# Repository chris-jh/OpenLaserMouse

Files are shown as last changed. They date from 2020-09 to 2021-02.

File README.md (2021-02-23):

# Open Laser Mouse
 Quadrature Optical Mouse Replacement Using an Arduino for the Amiga Tank Mouse

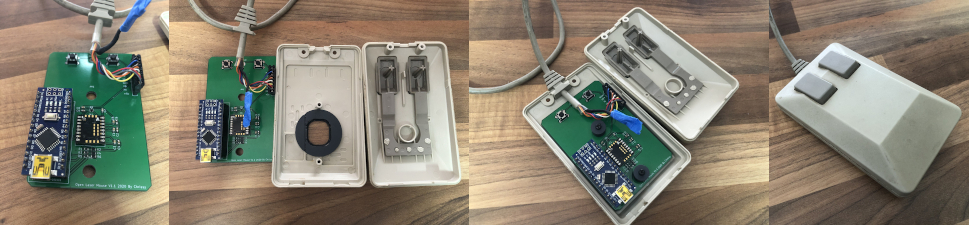
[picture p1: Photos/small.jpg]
PCB


Version 1.4.1
Copyright 2020 Chrissy

* Updated 3D Lens Cover

Version 1.4
Copyright 2020 Chrissy

* Added Atari ST SMD Version
  * Not Tested
  * Arduino is flipped 180° for ST version
  * Use same Amiga Pin definition in Arduino source if using original ST DE9 Connector.
* Fixed Wrong Fillplane selected. Corrected it back to GND.

Version 1.3
Copyright 2020 Chrissy

* ADNS9800 interface based on code from https://github.com/mrjohnk/ADNS-9800
* QUADRATURE interface based on blog from http://danceswithferrets.org/geekblog/?p=742

Two versions of the PCB, a SMD version (v1.1 Tested, not v1.3 yet) and a THT version which is currently untested.

Requires an Arduino Nano and a ADNS9800 Laser, which you can get still get from Aliexpress. Make sure to also get the Lens.

[**SMD Interactive BOM**][IBOMSMD]

[**THT Interactive BOM**][IBOMTHT]

Gerbers have been created from the recommendations at JLCPCB.

(https://support.jlcpcb.com/article/102-kicad-515---generating-gerber-and-drill-files)

You may need to re-generate for your chosen PCB Manufacturer

get the 1.2mm PCB Thickness or get smaller height tact switches if you use 1.6mm thickness. It is a tight tolerance between the tact switch mouse buttons and the posts on the mouse buttons.

---

## 3D Printable Lens Cover

3D Printable Lens Cover still requires testing, Sketchup model file is included to modify for tolerances of your printer.
<br>Only for Amiga SMD Version at the moment

***Print Settings***

* Layer Height : 1.5mm
* Print Speed : 25 mm/s
* Initial Layer Speed: 15mm
* Support: Yes
* Infill: 20%
* Line Width: 0.4mm
* Print Thin Walls: Yes
* Filter Out Tiny Gaps: Yes

3D printed on a Ender 3 using Cura

A fully printable Amiga Tank Mouse is available here

https://www.myminifactory.com/object/3d-print-amiga-tank-mouse-all-parts-are-ultra-detailed-100-size-104702

Although looks tough to print :)

---

## !!!!! WARNING !!!!!
Don't Plug in the USB to the Arduino while connected to the Amiga/Computer, as this will join the 5V together and may damage something.

This is still a work in progress, use at your own risk. I accept no responsibility if this damages any of your equipment.

[IBOMSMD]: http://htmlpreview.github.io/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
[IBOMTHT]: http://htmlpreview.github.io/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

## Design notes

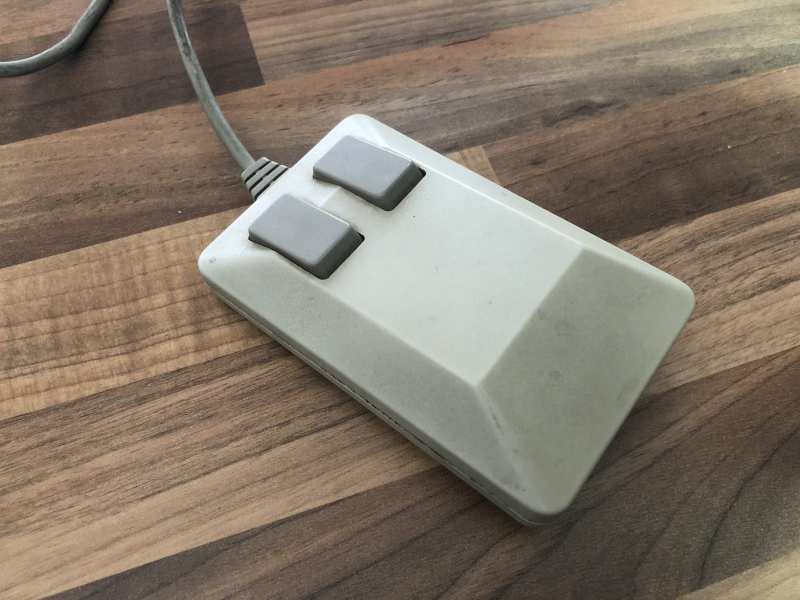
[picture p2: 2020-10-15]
Photos/mouse1.jpg

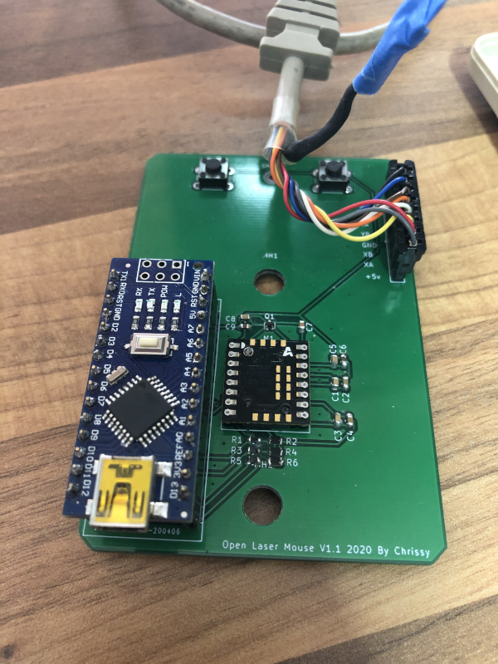
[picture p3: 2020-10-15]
Photos/board_front.jpg

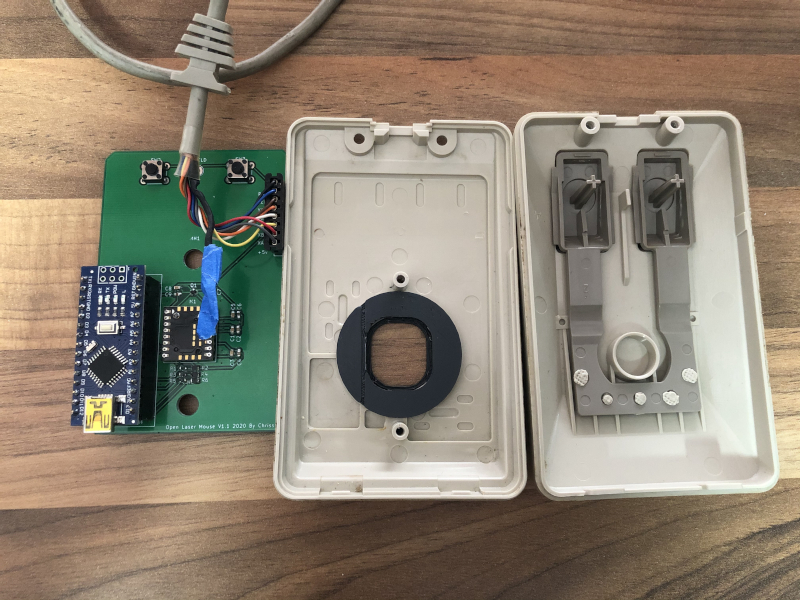
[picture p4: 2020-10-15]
Photos/mouse4.jpg

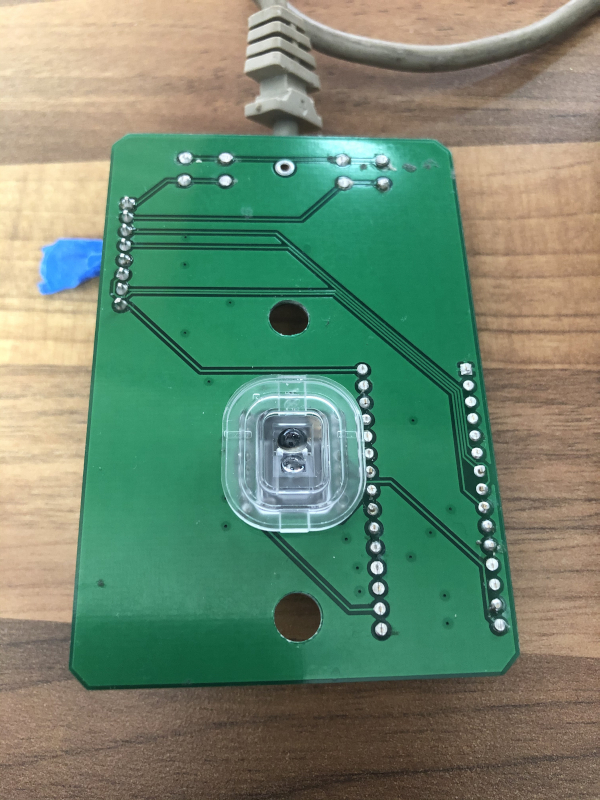
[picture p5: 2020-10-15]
Photos/board_back.jpg

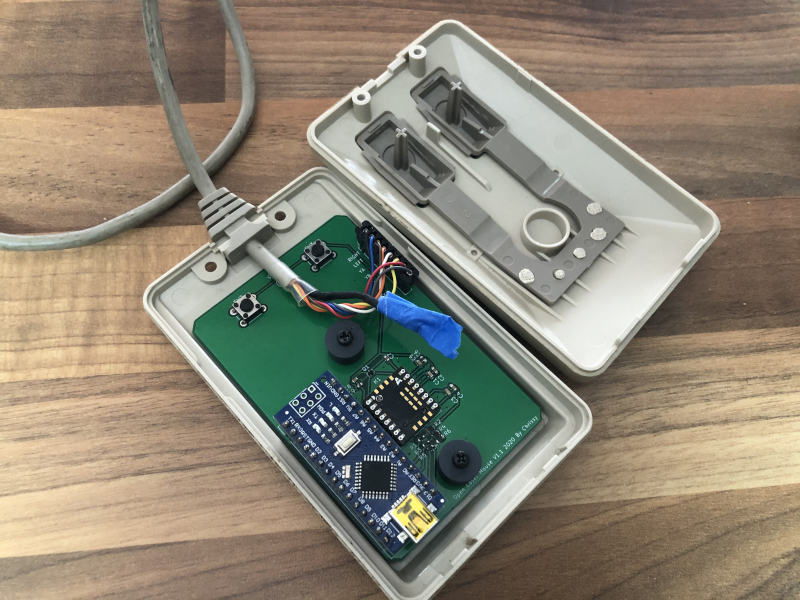
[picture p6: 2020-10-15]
Photos/mouse3.jpg

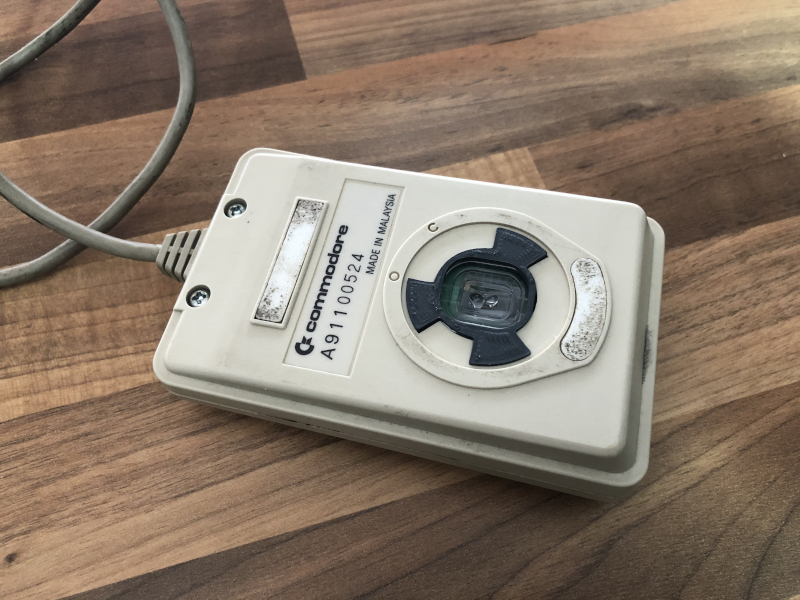
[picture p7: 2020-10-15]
Photos/mouse2.jpg

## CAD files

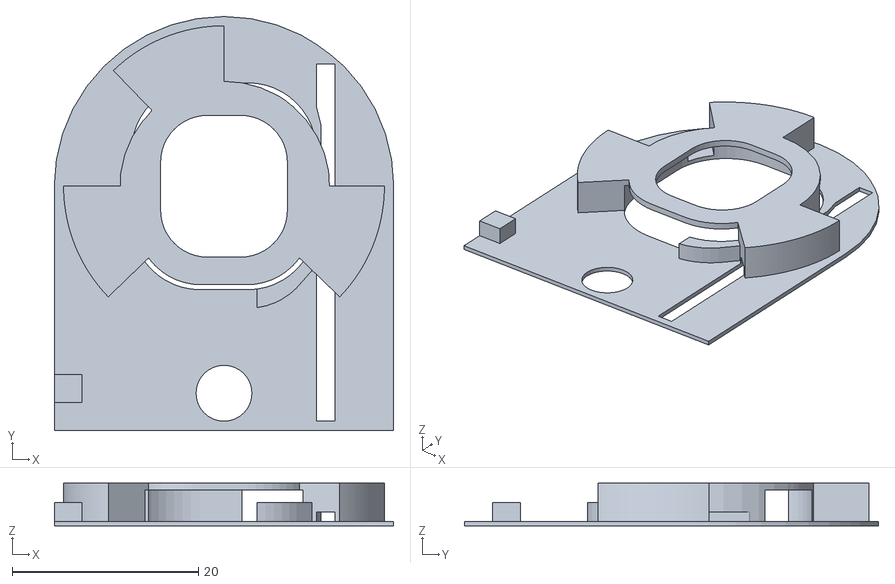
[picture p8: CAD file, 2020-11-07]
MouseLensCover/MouseLensCover.stl
36.5 x 44.4 x 4.60

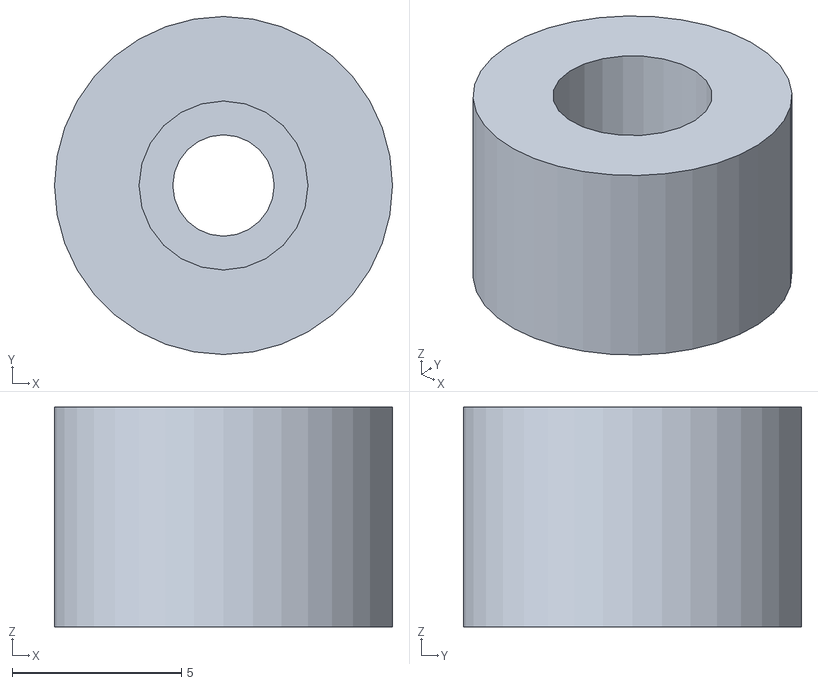
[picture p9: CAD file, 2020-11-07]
MouseLensCover/MouseLensCoverScrewHolder.stl
10.0 x 10.00 x 6.50

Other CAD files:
MouseLensCover/MouseLensCover.skp
MouseLensCover/MouseLensCover~.skp

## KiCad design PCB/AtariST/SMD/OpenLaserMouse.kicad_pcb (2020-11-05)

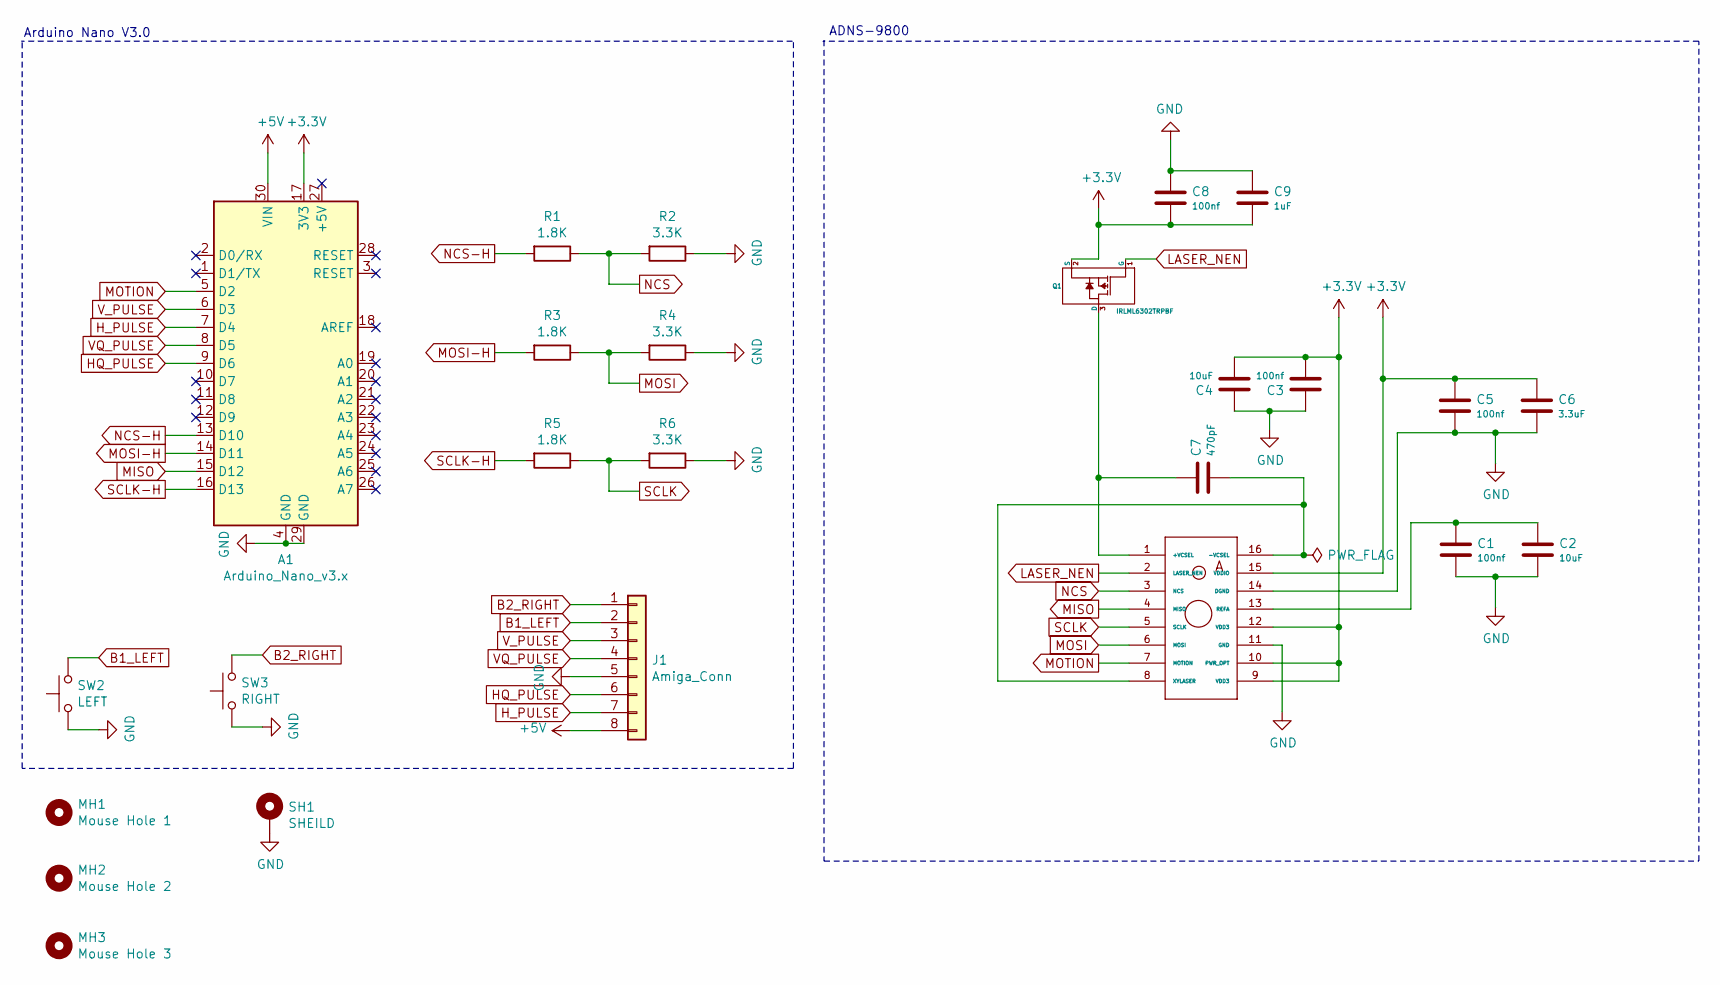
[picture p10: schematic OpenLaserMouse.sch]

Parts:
A1: Arduino_Nano_v3.x; Arduino_Nano
C1, C3, C5, C8: 100nf; C_0805_2012Metric
C2, C4: 10uF; C_0805_2012Metric
C6: 3.3uF; C_0805_2012Metric
C7: 470pF; C_0805_2012Metric
C9: 1uF; C_0805_2012Metric
J1: Amiga_Conn; PinHeader_1x08_P2.54mm_Vertical
M1: ADNS-9800
MH1: Mouse Hole 1; MountingHole_5.3mm_M5
MH2: Mouse Hole 2; MountingHole_5.3mm_M5
MH3: Mouse Hole 3; MountingHole_5.3mm_M5
Q1: IRLML6302TRPBF; SOT-23
R1, R3, R5: 1.8K; R_0805_2012Metric
R2, R4, R6: 3.3K; R_0805_2012Metric
SH1: SHEILD; Pin_D1.3mm_L11.0mm_LooseFit
SW2: LEFT; SW_PUSH_6mm
SW3: RIGHT; SW_PUSH_6mm

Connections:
+3V3: A1.17 (3V3), C3.2, C4.2, C5.1, C6.1, C8.2, C9.2, M1.9 (VDD3), M1.10 (PWR_OPT), M1.12 (VDD3), M1.15 (VDDIO), Q1.2 (S)
+5V: A1.30 (VIN), J1.8
B1_LEFT: J1.2, SW2.2
B2_RIGHT: J1.1, SW3.2
GND: A1.4 (GND), A1.29 (GND), C1.2, C2.2, C3.1, C4.1, C5.2, C6.2, C8.1, C9.1, J1.5, M1.11 (GND), M1.14 (DGND), R2.1, R4.1, R6.1, SH1.1, SW2.1, SW3.1
HQ_PULSE: A1.9 (D6), J1.6
H_PULSE: A1.7 (D4), J1.7
LASER_NEN: M1.2 (LASER_NEN), Q1.1 (G)
MISO: A1.15 (D12), M1.4 (MISO)
MOSI: M1.6 (MOSI), R3.1, R4.2
MOSI-H: A1.14 (D11), R3.2
MOTION: A1.5 (D2), M1.7 (MOTION)
NCS: M1.3 (NCS), R1.1, R2.2
NCS-H: A1.13 (D10), R1.2
unnamed: C1.1, C2.1, M1.13 (REFA)
unnamed: C7.1, M1.1 (+VCSEL), Q1.3 (D)
unnamed: C7.2, M1.8 (XYLASER), M1.16 (-VCSEL)
SCLK: M1.5 (SCLK), R5.1, R6.2
SCLK-H: A1.16 (D13), R5.2
VQ_PULSE: A1.8 (D5), J1.4
V_PULSE: A1.6 (D3), J1.3

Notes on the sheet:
ADNS-9800
Arduino Nano V3.0

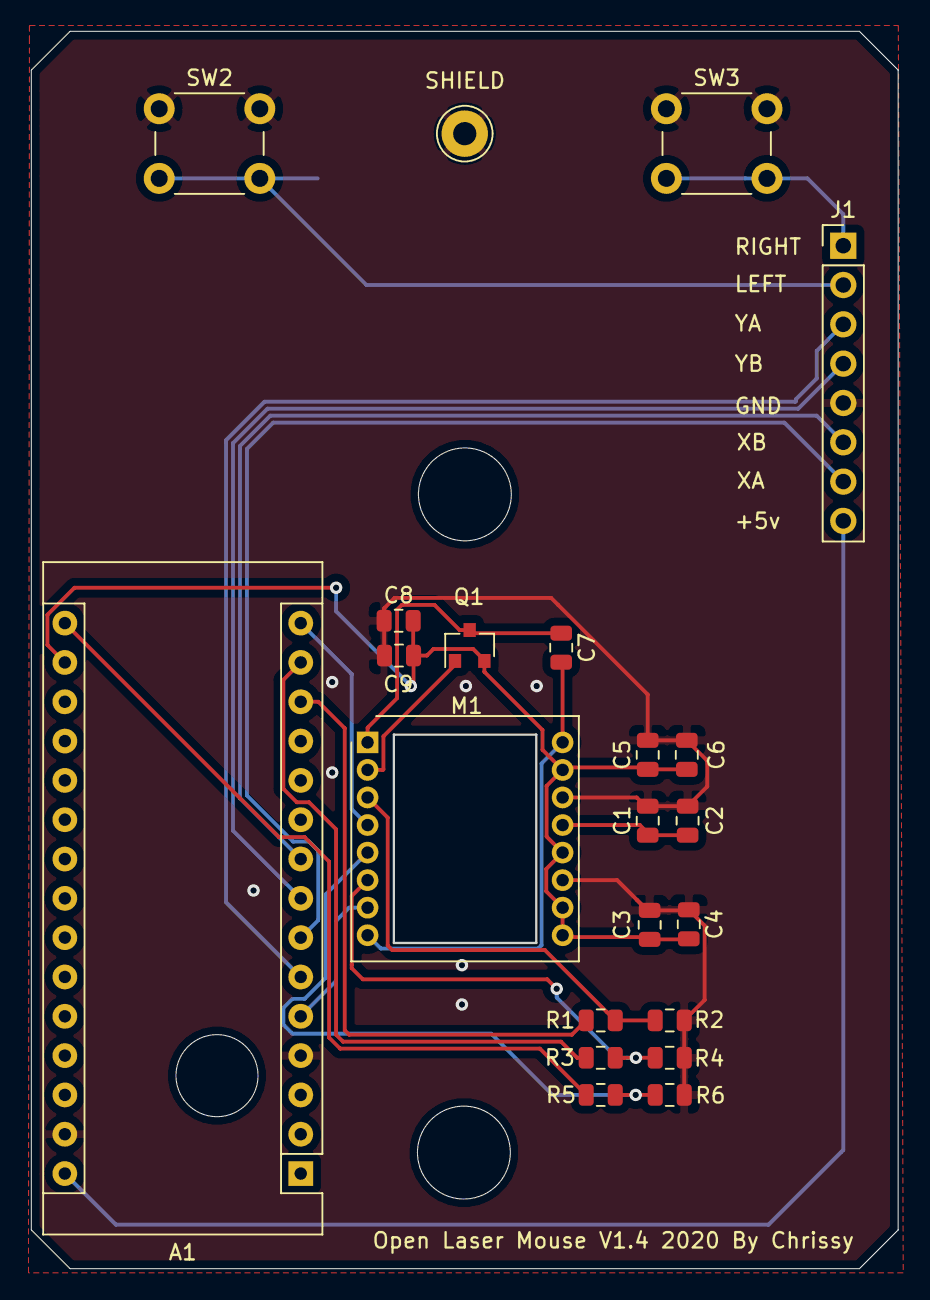
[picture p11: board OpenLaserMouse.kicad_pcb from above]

Board: 2 copper layers, 56.0 x 79.9 mm, 25 parts (0 on the bottom side), 21 nets.

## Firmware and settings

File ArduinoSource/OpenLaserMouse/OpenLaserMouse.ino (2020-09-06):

/*
 * Open Laser Mouse
 * By Chrissy
 * Version 1.3
 * Copyright 2020
 * 
 * ADNS9800 interface based on code from https://github.com/mrjohnk/ADNS-9800
 * QUADRATURE interface based on blog from http://danceswithferrets.org/geekblog/?p=742
 * 
 * 
 * !!!!! WARNING !!!!!
 * 
 * Don't Plug in the USB to the Arduino while connected to the Amiga/Computer, as this will join the 5V together and may damage something.
 * 
 * !!!!! WARNING !!!!!
 * 
 */
 
#include <SPI.h>
#define PIN_NCS    10
#define PIN_MOTION 0

//AMIGA PIN OUT
#define PIN_XA   4 //AMIGA PIN 2
#define PIN_XB   6 //AMIGA PIN 4
#define PIN_YA   3 //AMIGA PIN 3
#define PIN_YB   5 //AMIGA PIN 1

//ATARI ST PIN OUT
//#define PIN_XA   4 //ATARI ST PIN 2
//#define PIN_XB   5 //ATARI ST PIN 1
//#define PIN_YA   3 //ATARI ST PIN 3
//#define PIN_YB   6 //ATARI ST PIN 4


//MOTION SPEED CONTROL
//#define FAST //UNCOMMENT TO MAKE AS FAST AS POSSIBLE
unsigned long delayX = 0;
unsigned long delayY = 0;
const unsigned long delayBy = 100; //ALTER THIS TO CHANGE MOUSE SPEED, HIGHER NUMBER SLOWER

//QUADRATURE INDEXING (PULSES)
const bool chan1[] = {HIGH, HIGH, LOW, LOW};
const bool chan2[] = {HIGH, LOW, LOW, HIGH};
signed int xIndex, yIndex = 0;

//MAIN SETUP
void setup() {
  delay(2000);
  Serial.begin(9600);
  setupSPI();
  if (setupADNS()){
    setupQuadrature();
    #ifdef FAST
      attachInterrupt(PIN_MOTION, readMotion, FALLING); //Not sure to have this, or just read in loop
    #endif
  }
}

//SETUP SPI TO TALK TO THE ADNS9800
void setupSPI(){
  Serial.println("Init SPI");
  pinMode(PIN_NCS, OUTPUT);
  pinMode(PIN_MOTION, INPUT_PULLUP); 
  SPI.begin();
  SPI.setDataMode(SPI_MODE3);
  SPI.setBitOrder(MSBFIRST);
  SPI.setClockDivider(8);
  delay(100);
}

//SETUP THE QUADRATURE
void setupQuadrature() {
  Serial.println("Init Quadrature");
  pinMode(PIN_XA, OUTPUT);
  pinMode(PIN_XB, OUTPUT);
  pinMode(PIN_YA, OUTPUT);
  pinMode(PIN_YB, OUTPUT);
  digitalWrite(PIN_XA, HIGH);
  digitalWrite(PIN_XB, HIGH);
  digitalWrite(PIN_YA, HIGH);
  digitalWrite(PIN_YB, HIGH);
}

//MAIN LOOP
void loop() {
  #ifndef FAST
    readMotion();
  #endif
}

//READ THE MOUSE MOTION ON HOW FAR IT HAS CURRENTLY TRAVELLED AND PULSE THE AMIGA THE DISTANCE
void readMotion(){
  volatile int* xydat = readADNS();
  signed int mX = convTwosComp(xydat[1]);
  signed int mY = convTwosComp(xydat[3]);
  pulse(mX, mY);
}

//PULSE THE AMIGA
void pulse(signed int mX, signed int mY){
  bool rX = (mX <= 0); //Check Reverse
  bool rY = (mY <= 0); //Check Reverse

  mX = abs(mX); //Make it positive
  mY = abs(mY); //Make it positive

  while (mX || mY) { //May Need Timer Delays ??????
    if (mX > 0 && doX()){
      xIndex = (rX ? xIndex + 1 : xIndex - 1);
      if (xIndex < 0) xIndex = 3; else if (xIndex > 3) xIndex = 0;
      mX--;
      pulseX(xIndex);
    }

    if (mY > 0 && doY()){
      yIndex = rY ? yIndex + 1 : yIndex - 1;
      if (yIndex < 0) yIndex = 3; else if (yIndex > 3) yIndex = 0;
      mY--;
      pulseY(yIndex);
    } 
  }
  readADNS(); //Clear ADNS Buffer ready for new read
}

//PULSE THE QUADRATURE X
void pulseX(signed int index) {
  digitalWrite(PIN_XA, chan1[index]);
  digitalWrite(PIN_XB, chan2[index]);
}

//PULSE THE QUADRATURE Y
void pulseY(signed int index) {
  digitalWrite(PIN_YA, chan1[index]);
  digitalWrite(PIN_YB, chan2[index]);
}


//UTILS
int convTwosComp(int b){
  if(b & 0x80){
    b = -1 * ((b ^ 0xff) + 1);
  }
  return b;
}

bool doX(){
  #ifdef FAST
    return true;
  #else
    if ((micros() > delayX)){
      delayX = micros() + delayBy;
      return true;
    }
    return false;
  #endif
}

bool doY(){
  #ifdef FAST
    return true;
  #else
    if ((micros() > delayY)){
      delayY = micros() + delayBy;
      return true;
    }
    return false;
  #endif
}

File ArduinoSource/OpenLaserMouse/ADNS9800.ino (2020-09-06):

#include <SPI.h>

#include <avr/pgmspace.h> // for progmem (storing the firmware in flash instead of in SRAM)
extern const unsigned short firmware_length = 3070;
extern const unsigned char firmware_data[] PROGMEM = {
0x03, 0xa4, 0x6e, 0x16, 0x6d, 0x89, 0x3e, 0xfe, 0x5f, 0x1c, 0xb8, 0xf2, 0x47, 0x0c, 0x7b, 
0x74, 0x6a, 0x56, 0x0f, 0x7d, 0x76, 0x71, 0x4b, 0x0c, 0x97, 0xb6, 0xcf, 0xfd, 0x78, 0x72, 
0x66, 0x2f, 0xbd, 0xf8, 0x53, 0x24, 0xab, 0xd4, 0x2c, 0xb0, 0xe4, 0x32, 0xf1, 0x6a, 0x56, 
0x2e, 0xbf, 0xfc, 0x7a, 0x57, 0x0d, 0x79, 0x70, 0x66, 0x46, 0x0e, 0x7f, 0x5d, 0x19, 0x91, 
0xaa, 0xc2, 0x0d, 0x8e, 0x7f, 0x5d, 0x19, 0xb0, 0xe2, 0x46, 0xef, 0x5c, 0x3a, 0xd7, 0x2c, 
0xbb, 0xf4, 0x6a, 0x37, 0xcd, 0x18, 0xb2, 0xc7, 0x0c, 0x9a, 0x97, 0x8f, 0x52, 0xfd, 0x0d, 
0xb8, 0x41, 0x00, 0x9e, 0x8e, 0x9a, 0x1e, 0x6d, 0x0c, 0xe2, 0xaa, 0x13, 0x93, 0xb8, 0xc1, 
0x2a, 0x29, 0xbb, 0x0b, 0xe3, 0x71, 0x08, 0x6d, 0xfd, 0xb6, 0xd9, 0xcf, 0x65, 0x21, 0x27, 
0x45, 0x1b, 0xbe, 0xe2, 0x61, 0x86, 0x3c, 0xbf, 0x68, 0x9c, 0xd6, 0x75, 0x01, 0x5e, 0xe0, 
0xc6, 0x92, 0x79, 0xf4, 0x6a, 0xa9, 0xbb, 0x2a, 0x79, 0xd0, 0xe1, 0x5c, 0x32, 0xb1, 0x5a, 
0x1b, 0xba, 0xaf, 0x11, 0xea, 0x24, 0x6a, 0x83, 0x4f, 0x8d, 0xed, 0x19, 0x62, 0x70, 0x54, 
0xfb, 0x0e, 0x1f, 0x83, 0xcc, 0xf0, 0xb7, 0xae, 0x05, 0xd3, 0x42, 0x5d, 0x48, 0xa0, 0x7a, 
0x0b, 0x73, 0xb3, 0xc8, 0xa6, 0xb7, 0x1b, 0x08, 0x13, 0x9b, 0x89, 0x44, 0x42, 0xae, 0xd8, 
0x6a, 0xba, 0x9b, 0x84, 0x25, 0x8b, 0xa4, 0x5e, 0x0b, 0x85, 0xb0, 0x8f, 0x8d, 0x80, 0x9c, 
0xd1, 0x52, 0xc7, 0xcb, 0xff, 0x8d, 0x8b, 0xdd, 0x87, 0xf2, 0x63, 0xca, 0xe7, 0x4f, 0x4a, 
0x57, 0x3c, 0xdf, 0xaf, 0xcb, 0x5c, 0xbb, 0x39, 0x0b, 0x01, 0x9c, 0x79, 0x22, 0x15, 0xb8, 
0xa0, 0xd3, 0x72, 0x02, 0x35, 0x20, 0x40, 0xe0, 0x17, 0xde, 0x89, 0x88, 0xce, 0xe9, 0x2b, 
0x75, 0xba, 0xa0, 0x96, 0x24, 0x1e, 0x71, 0xb5, 0x15, 0x00, 0x61, 0xe0, 0x5c, 0x93, 0x4e, 
0xea, 0x53, 0xd0, 0xfc, 0xef, 0xae, 0x2b, 0xeb, 0x8f, 0xc7, 0x69, 0x68, 0xc7, 0xfc, 0x1a, 
0x1f, 0x41, 0x0d, 0xd0, 0xc1, 0x03, 0xaf, 0xc9, 0xfd, 0xe4, 0x21, 0x43, 0xc4, 0xef, 0xc2, 
0xdd, 0x7b, 0x73, 0xbc, 0xca, 0xf4, 0xa5, 0x2e, 0x83, 0x90, 0x1f, 0x78, 0x41, 0xc3, 0x13, 
0x8e, 0x95, 0x0a, 0x57, 0xdf, 0x0a, 0x87, 0x40, 0x2b, 0xd9, 0xba, 0x56, 0x59, 0x9d, 0x2c, 
0xb2, 0xb8, 0xb3, 0xfb, 0x77, 0x78, 0x3a, 0xef, 0xbf, 0x2d, 0xc8, 0xb9, 0x94, 0x62, 0x47, 
0x92, 0x98, 0x42, 0x23, 0x07, 0xd9, 0x39, 0x46, 0x5e, 0x6f, 0xe0, 0x46, 0x14, 0x0e, 0x3d, 
0x74, 0x40, 0x21, 0xb4, 0x67, 0x05, 0xa8, 0xe2, 0x12, 0x93, 0x41, 0xc2, 0x80, 0xb9, 0x56, 
0x4b, 0xf9, 0x5a, 0x15, 0x9c, 0x37, 0xc4, 0x4b, 0x05, 0xad, 0x5a, 0xaf, 0xa1, 0x3e, 0xe4, 
0x6e, 0xc5, 0x91, 0xb6, 0x75, 0x7d, 0x1b, 0xe4, 0xc5, 0x4d, 0x28, 0x6b, 0xe9, 0xad, 0x20, 
0x8b, 0x64, 0x91, 0x57, 0x4f, 0xdf, 0x9a, 0x97, 0x7e, 0xbe, 0x8e, 0xd6, 0xd6, 0x3b, 0x17, 
0xf9, 0x19, 0x28, 0xb2, 0x2e, 0x8f, 0x26, 0xb4, 0x9b, 0xe5, 0xde, 0x0f, 0x8d, 0x0a, 0x9a, 
0x9d, 0x1b, 0xde, 0x6f, 0xcb, 0x84, 0xba, 0x26, 0xd0, 0x12, 0xef, 0x30, 0x38, 0x43, 0xac, 
0xb7, 0xa7, 0xef, 0x09, 0x7c, 0x52, 0x27, 0xfc, 0x2e, 0xab, 0x50, 0xa0, 0x21, 0x40, 0xe7, 
0xc1, 0x5f, 0x02, 0x41, 0x84, 0xa8, 0x54, 0xa8, 0x2e, 0x37, 0x6f, 0xd8, 0xb1, 0xa4, 0xd0, 
0x75, 0xef, 0x31, 0xca, 0x54, 0x1e, 0x33, 0xad, 0x19, 0xa1, 0x94, 0xbc, 0x1b, 0x34, 0x6c, 
0xfb, 0x5f, 0xcc, 0x45, 0x76, 0xc8, 0x96, 0xce, 0x1c, 0x3a, 0x0e, 0x77, 0xed, 0xd8, 0xd2, 
0x96, 0xac, 0x77, 0x30, 0xe1, 0xef, 0xb0, 0x33, 0xf0, 0x6e, 0x3d, 0xce, 0x5e, 0x6d, 0xde, 
0x8a, 0xdc, 0x9b, 0x91, 0x63, 0x2a, 0x95, 0x20, 0x0d, 0xfd, 0x78, 0xba, 0xcb, 0x15, 0x43, 
0xc9, 0x20, 0x96, 0x83, 0x06, 0xd9, 0x11, 0xf3, 0xe2, 0x13, 0xcf, 0x9c, 0x91, 0x7f, 0x33, 
0x46, 0xa7, 0xe2, 0xd3, 0x75, 0xff, 0x4f, 0x0c, 0x0c, 0xaf, 0xcd, 0xa6, 0x9c, 0xa6, 0x73, 
0xe2, 0x6d, 0x17, 0x16, 0xb5, 0x99, 0x80, 0x35, 0xd9, 0x61, 0xf3, 0x48, 0x23, 0xff, 0xae, 
0x53, 0x89, 0xfa, 0x55, 0x1c, 0x37, 0xa5, 0xe8, 0x62, 0x12, 0xb2, 0x22, 0x04, 0xed, 0x42, 
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


//--------------------------------------------------------------
//                          ADNS
//--------------------------------------------------------------

// Registers
#define REG_Product_ID                           0x00
#define REG_Revision_ID                          0x01
#define REG_Motion                               0x02
#define REG_Delta_X_L                            0x03
#define REG_Delta_X_H                            0x04
#define REG_Delta_Y_L                            0x05
#define REG_Delta_Y_H                            0x06
#define REG_SQUAL                                0x07
#define REG_Pixel_Sum                            0x08
#define REG_Maximum_Pixel                        0x09
#define REG_Minimum_Pixel                        0x0a
#define REG_Shutter_Lower                        0x0b
#define REG_Shutter_Upper                        0x0c
#define REG_Frame_Period_Lower                   0x0d
#define REG_Frame_Period_Upper                   0x0e
#define REG_Configuration_I                      0x0f
#define REG_Configuration_II                     0x10
#define REG_Frame_Capture                        0x12
#define REG_SROM_Enable                          0x13
#define REG_Run_Downshift                        0x14
#define REG_Rest1_Rate                           0x15
#define REG_Rest1_Downshift                      0x16
#define REG_Rest2_Rate                           0x17
#define REG_Rest2_Downshift                      0x18
#define REG_Rest3_Rate                           0x19
#define REG_Frame_Period_Max_Bound_Lower         0x1a
#define REG_Frame_Period_Max_Bound_Upper         0x1b
#define REG_Frame_Period_Min_Bound_Lower         0x1c
#define REG_Frame_Period_Min_Bound_Upper         0x1d
#define REG_Shutter_Max_Bound_Lower              0x1e
#define REG_Shutter_Max_Bound_Upper              0x1f
#define REG_LASER_CTRL0                          0x20
#define REG_Observation                          0x24
#define REG_Data_Out_Lower                       0x25
#define REG_Data_Out_Upper                       0x26
#define REG_SROM_ID                              0x2a
#define REG_Lift_Detection_Thr                   0x2e
#define REG_Configuration_V                      0x2f
#define REG_Configuration_IV                     0x39
#define REG_Power_Up_Reset                       0x3a
#define REG_Shutdown                             0x3b
#define REG_Inverse_Product_ID                   0x3f
#define REG_Motion_Burst                         0x50
#define REG_SROM_Load_Burst                      0x62
#define REG_Pixel_Burst                          0x64

volatile int xydat[5];

void adns_com_begin(){
  digitalWrite(PIN_NCS, LOW);
}

void adns_com_end(){
  digitalWrite(PIN_NCS, HIGH);
}
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

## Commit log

2020-09-06 Version fix
    Updated so all version numbers on PCB's and Code are the same
    [OpenLaserMouse.ino]
2020-09-12 Added BOM
    Added Interactive BOM
2020-09-12 Added THT BOM
    Added BOM
2020-10-14 Adjustments and Photos
    Adjusted Mouting Holes on the PCB's
    Added Photos of V1.1
    Tidy up
    [MouseLensCover.skp, MouseLensCover.stl, MouseLensCoverScrewHolder.stl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]
2020-10-15 Added Gerbers
    Added Gerbers
    More Readme Tidy up
    [OpenLaserMouse-B_Cu.gbr, OpenLaserMouse-B_Mask.gbr, OpenLaserMouse-B_SilkS.gbr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]
2020-11-05 Added ST Mouse PCB
    Added ST Mouse PCB
    Fixed Wrong Fillplane on Amiga PCB
    [OpenLaserMouse-B_Cu.gbr, OpenLaserMouse-B_Mask.gbr, OpenLaserMouse-B_SilkS.gbr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]
2020-11-07 Update to 3D Print Lens Cover
    Update to 3D Print Lens Cover
    [MouseLensCover.skp, MouseLensCover.stl, MouseLensCoverScrewHolder.stl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]
